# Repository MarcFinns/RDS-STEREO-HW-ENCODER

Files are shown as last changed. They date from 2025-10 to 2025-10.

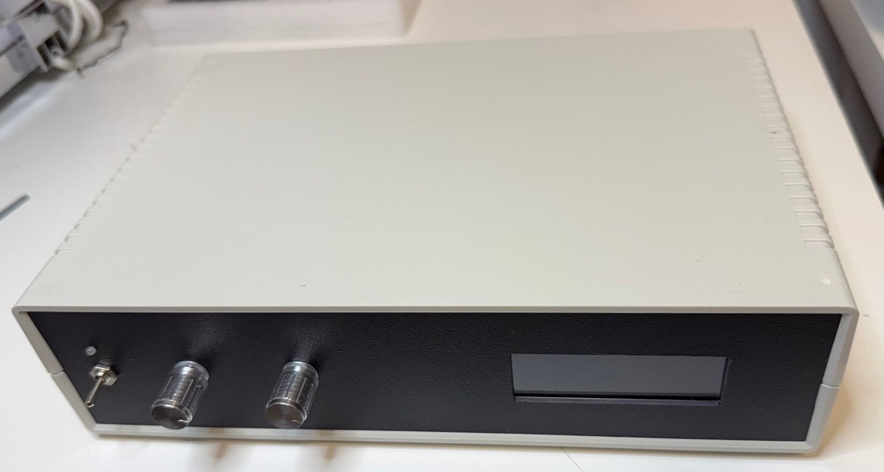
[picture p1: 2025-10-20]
PICTURES/Case.jpeg

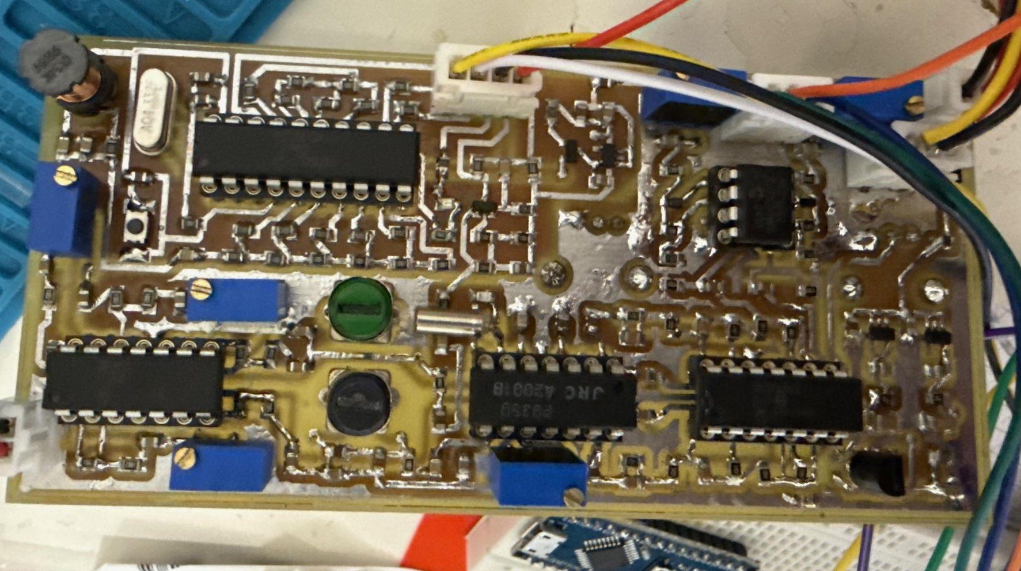
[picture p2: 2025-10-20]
PICTURES/Signal Processing PCB.jpeg

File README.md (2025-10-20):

# RDS Stereo Encoder for FM radio 

A hardware RDS Stereo Encoder for FM radio comprised of:
- A signal processing board
- A digital board that provides a transparent communication bridge between PC RDS software and the DS encoder chips, while simultaneously providing real-time visual display of RDS data (PS/RT) and audio levels (VU meters) on a TFT display.

## System Overview

This project specifically describes the software implementation of the digital board. The schematic and PCB of the whole system are in the **HARDWARE** folder.

### Key Features

- **Dual-core ESP32 processing** for optimal performance
- **FreeRTOS task-based design** with priority optimization
- **Queue-based inter-task communication** for thread safety
- **Collision avoidance system** for seamless PC-MRDS1322 bridging
- **Real-time graphics** with ~60 FPS VU meter updates
- **Professional VU meters** with color-coded zones and peak detection

## Hardware Requirements

### Main Components
- **ESP32 DevKit** (dual-core processing)
- **MRDS1322 RDS encoder chip**
- **NV3007 428x142 TFT display**
- **Dual-channel audio input** for VU meters

### Hardware Design Files

The **`hardware/`** folder contains the complete PCB design for this project, including schematics and PCB layout. This hardware has been **built and fully tested** in real-world conditions.

### MRDS1322 RDS Encoder

The **MRDS1322** RDS encoder chip is from [Pira.cz](http://pira.cz). Datasheet available in the `hardware/` folder. Use the **TinyRDS** Windows program (also from Pira.cz) to send RDS data through this ESP32 bridge to the encoder.

## Pin Assignments

### TFT Display (NV3007) - SPI Interface
```
ESP32 Pin | Function    | NV3007 Pin
----------|-------------|-------------
GPIO19    | SCLK        | SCK
GPIO18    | MOSI        | SDA
GPIO16    | CS          | CS
GPIO17    | DC/RS       | DC
GPIO5     | RST         | RES
GPIO4     | Backlight   | LED
3.3V      | Power       | VCC
GND       | Ground      | GND
```

### Serial Communication
```
Interface | ESP32 Pin    | Baud Rate | Purpose
----------|------------- |-----------|------------------
Serial    | USB          | 19200     | PC Communication
Serial1   | GPIO21 (RX)  | 19200     | MRDS1322 RDS Chip
          | GPIO22 (TX)  |           |
```

### VU Meters - Audio Input (ADC)
```
Channel | ESP32 Pin | ADC Channel | Purpose
--------|-----------|-------------|----------------
Left    | GPIO39    | ADC1_CH3    | Left audio input
Right   | GPIO36    | ADC1_CH0    | Right audio input
```

### Complete Pin Reference Table
All pin assignments are centralized in `SharedTypes.h` for easy modification:

```
┌──────────────┬─────────────────────┬──────────────────────────┐
│ ESP32 GPIO   │ Function            │ Connected To             │
├──────────────┼─────────────────────┼──────────────────────────┤
│ GPIO21       │ SERIAL1_RX          │ MRDS1322 TX              │
│ GPIO22       │ SERIAL1_TX          │ MRDS1322 RX              │
│ GPIO16       │ TFT_CS              │ NV3007 Chip Select       │
│ GPIO5        │ TFT_RST             │ NV3007 Reset             │
│ GPIO17       │ TFT_DC              │ NV3007 Data/Command      │
│ GPIO18       │ TFT_MOSI            │ NV3007 SPI Data          │
│ GPIO19       │ TFT_SCLK            │ NV3007 SPI Clock         │
│ GPIO4        │ TFT_BL              │ NV3007 Backlight         │
│ GPIO39 (A3)  │ PIN_L (ADC1_CH3)    │ Left Audio Input         │
│ GPIO36 (A0)  │ PIN_R (ADC1_CH0)    │ Right Audio Input        │
│ USB (N/A)    │ Serial (PC Comm)    │ PC USB Connection        │
└──────────────┴─────────────────────┴──────────────────────────┘
```

**Note**: All pin defines are located in `SharedTypes.h` lines 136-151. To change pin assignments for PCB design, simply modify the `#define` values in that single location.

## System Architecture

### Communication Flow
```
PC Software → Serial USB → ESP32 Core 0 → Serial1 → MRDS1322
                ↓              ↓
         Response Routing  PS/RT Monitoring
                ↓              ↓
            PC Software    Core 1 → TFT Display
                               ↓
                          VU Meters (GPIO36/39)
```

### Task Architecture
- **CommunicationManager** (Core 0, Priority 1): PC-MRDS1322 bridging
- **DisplayManager** (Core 1, Priority 2): TFT graphics + VU meters
- **Queue-based data exchange** for thread-safe operation

## Display Layout

### TFT Display (428x142, Landscape)
```
┌─────────────────────────────────┐ ← Y=10
│         STATION ID              │   Station area (30px tall)
│      (Cyan, Size 3)             │   Auto-centered, space-trimmed
├─────────────────────────────────┤ ← Y=38
│   Scrolling Radio Text...       │   Text area (25px tall)
│     (White, Size 2)             │   Sliding window scrolling
├─────────────────────────────────┤ ← Y=75
│ L ████████████████████████████  │   VU Left (18px tall)
│   |   |  |  ||  |     dB Scale  │   Professional scale with
│  -20 -10 -3  0 +3   (colored)   │   color-coded bold labels
│   |   |  |  ||  |               │
│ R ████████████████████████████  │   VU Right (18px tall)
└─────────────────────────────────┘ ← Y=142
```

### VU Meter Features
- **Color-coded bars**: Green (safe) → Yellow (loud) → Orange (hot) → Red (peak)
- **Professional dB scale**: Centered between bars with color-coded bold labels
  - **-20/-10 dB**: Green (safe levels)
  - **-3 dB**: Yellow (caution level)
  - **0 dB**: White (reference level)
  - **+3 dB**: Red (peak/overload warning)
- **Peak markers**: White bars showing recent maximum levels (1-second hold)
- **Smooth ballistics**: Fast attack, slow release for natural VU behavior

## MRDS1322 Protocol

### Memory Map
- **PS (Program Service)**: Address 0xC8, Length 8 bytes
- **RT (Radio Text)**: Address 0x20, Length 64 bytes

### Protocol Frame Structure
```
Read Command:  FE D0 [ADDR] [LEN] FF
Response:      FE [DATA...] FF

Byte Stuffing Rules:
- Data byte 0xFD → FD 00
- Data byte 0xFE → FD 01
- Data byte 0xFF → FD 02
```

## Configuration

### VU Meter Parameters
```cpp
#define SAMPLE_WINDOW 2       // Samples per level calculation
#define ATTACK_STEP 3         // Fast attack (pixels/step)
#define RELEASE_STEP 4        // Slow release (pixels/step)
#define DECAY_INTERVAL_MS 20  // Decay timing (20ms)
#define PEAK_HOLD_MS 1000     // Peak hold time (1 second)
```

### Text Scrolling
```cpp
#define SCROLL_DELAY_MS 50    // Base scroll timing (multiplied by 3 = 150ms actual)
#define SCROLL_STEP_SIZE 2    // Pixels to advance per step (smooth motion)
```

### Display Features
- **Station ID**: Auto-centers after trimming trailing spaces
- **Radio Text**: Sliding window scrolling for long text, centered for short text
- **VU Scale**: Professional dB scale with bold, color-coded labels

## Performance Specifications

- **VU Meter Update Rate**: ~60 FPS (16ms loop time)
- **Text Scroll Speed**: Character-by-character at ~6.7 FPS (150ms per step)
- **MRDS1322 Polling**: Every 2 seconds
- **Peak Marker Hold**: 1 second
- **Audio Sampling**: 12-bit ADC (0-4095 range)
- **Display Updates**: Change detection prevents unnecessary redraws

## Build Dependencies

### Required Libraries
```cpp
#include <Arduino.h>
#include <Arduino_GFX_Library.h>    // TFT display driver (NV3007)
#include "freertos/FreeRTOS.h"      // Real-time OS
#include "freertos/queue.h"         // Inter-task communication
#include "freertos/task.h"          // Task management
```

## File Structure

```
RDS_STEREO_ENCODER_CLEAN/
├── RDS_STEREO_ENCODER_CLEAN.ino  # Main Arduino sketch
├── CommunicationManager.h        # PC-MRDS1322 bridge header
├── CommunicationManager.cpp      # Communication implementation
├── DisplayManager.h              # Display management header
├── DisplayManager.cpp            # TFT/VU meter implementation
├── SharedTypes.h                 # Pin configuration & data structures
├── splashscreen.h                # Splash screen data header
├── splashscreen.cpp              # Splash screen bitmap data
└── README.md                     # This documentation
```

## Usage

1. **Hardware Setup**: Connect all components according to pin assignments
2. **Software Setup**: Install required libraries in Arduino IDE
3. **Configuration**: Adjust compile-time options in SharedTypes.h
4. **Upload**: Flash the code to ESP32 DevKit
5. **PC Software**: Connect RDS software to ESP32's Serial port at 19200 baud
6. **MRDS1322**: Connect RDS encoder chip to Serial1 at 19200 baud

## License

Created by Claude Code Assistant, 2024
Version 2.0

## Technical Notes

- The system uses ESP32's dual-core architecture for optimal performance
- Core 0 handles communication with lower priority for smooth graphics
- Core 1 handles display updates with higher priority for responsive VU meters
- Queue-based communication ensures thread-safe data exchange
- Change detection prevents unnecessary screen updates and reduces flicker
- Logarithmic audio scaling provides perceptual accuracy for VU meters

## Pin Configuration for PCB Design

All hardware pin assignments are centralized in **`SharedTypes.h`** (lines 136-151) under the section "ESP32 HARDWARE PIN CONFIGURATION". This design makes it easy to modify pins for custom PCB layouts:

1. **Serial Communication**: `SERIAL1_RX`, `SERIAL1_TX` (GPIO21/22)
2. **TFT Display**: `TFT_CS`, `TFT_RST`, `TFT_DC`, `TFT_MOSI`, `TFT_SCLK`, `TFT_BL` (GPIO16/5/17/18/19/4)
3. **VU Meter ADC**: `PIN_L`, `PIN_R` (GPIO39/36)

**To modify pins**: Simply edit the `#define` values in `SharedTypes.h`. The code automatically uses these definitions throughout - no need to search and replace in multiple files.

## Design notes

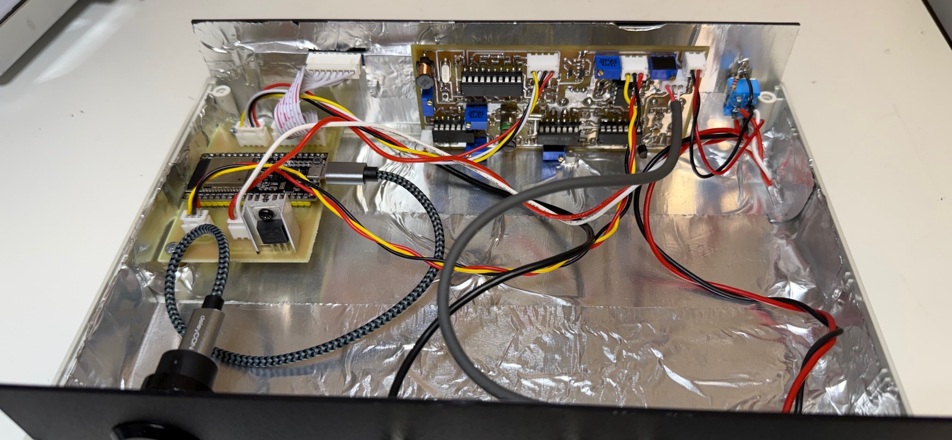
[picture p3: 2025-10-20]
PICTURES/Open case - back.jpeg

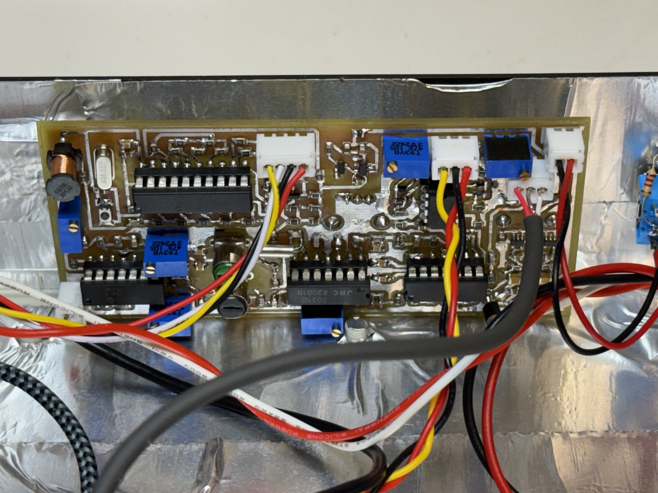
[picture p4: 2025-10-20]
PICTURES/Mounted Signal processing PCB.jpeg

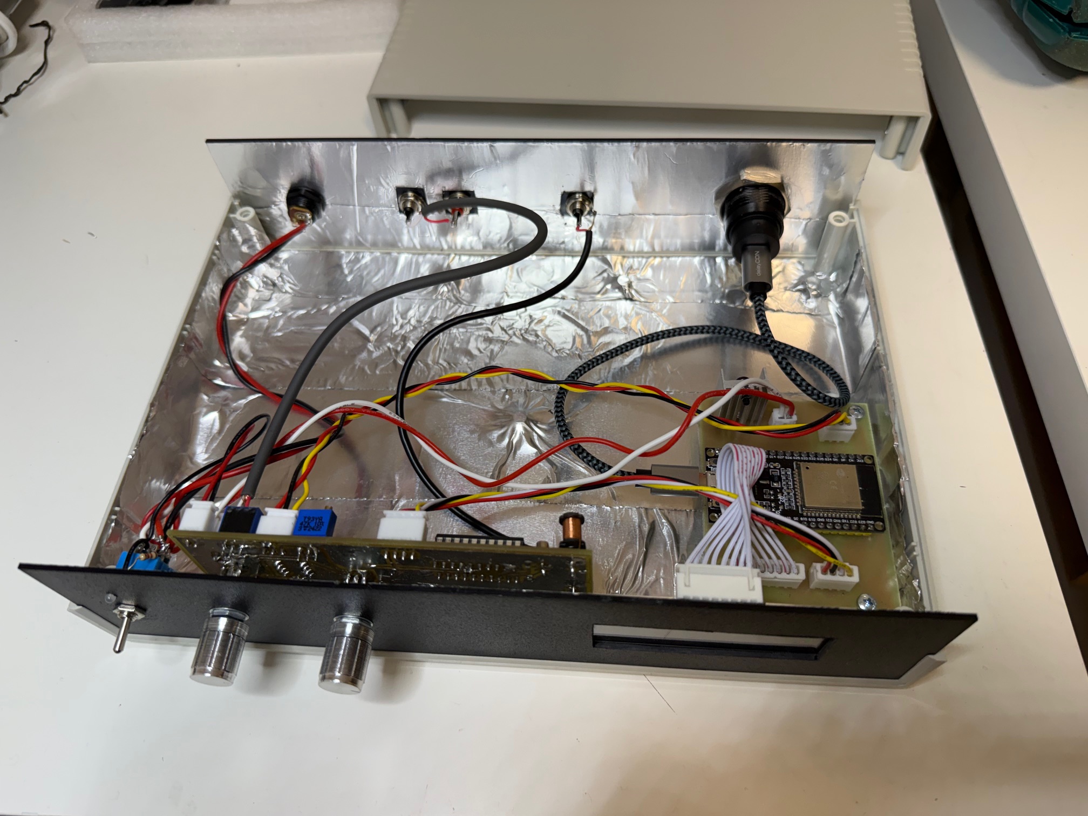
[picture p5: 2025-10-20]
PICTURES/Open case - front.jpeg

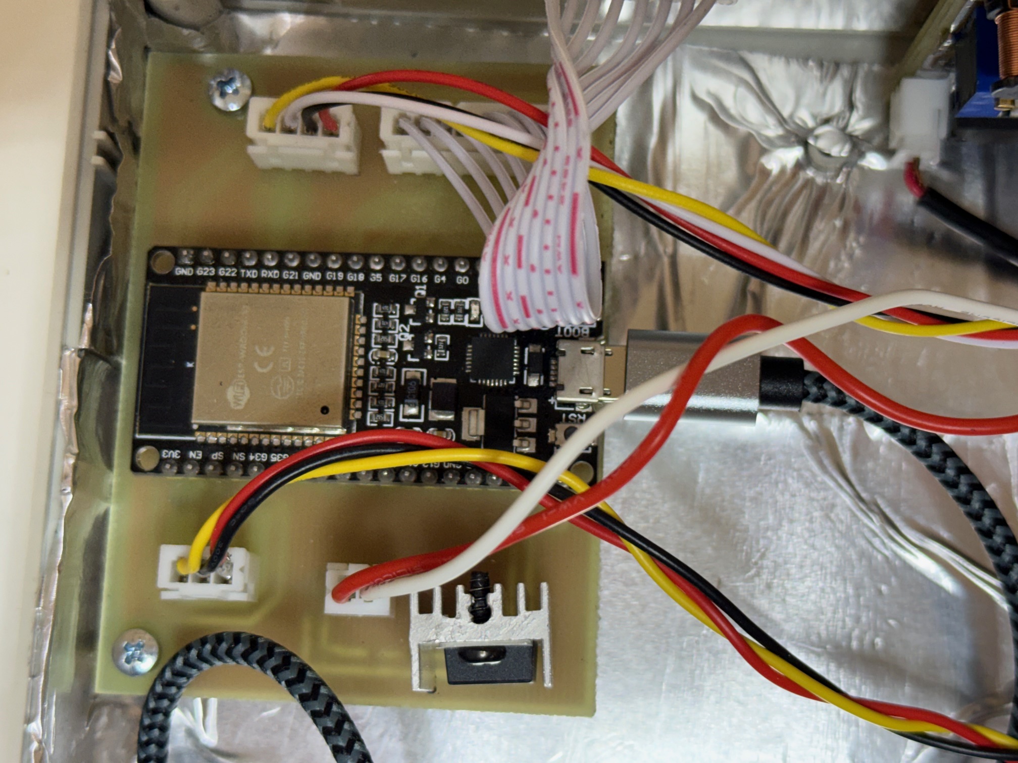
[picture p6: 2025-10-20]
PICTURES/Mounted Digital PCB.jpeg

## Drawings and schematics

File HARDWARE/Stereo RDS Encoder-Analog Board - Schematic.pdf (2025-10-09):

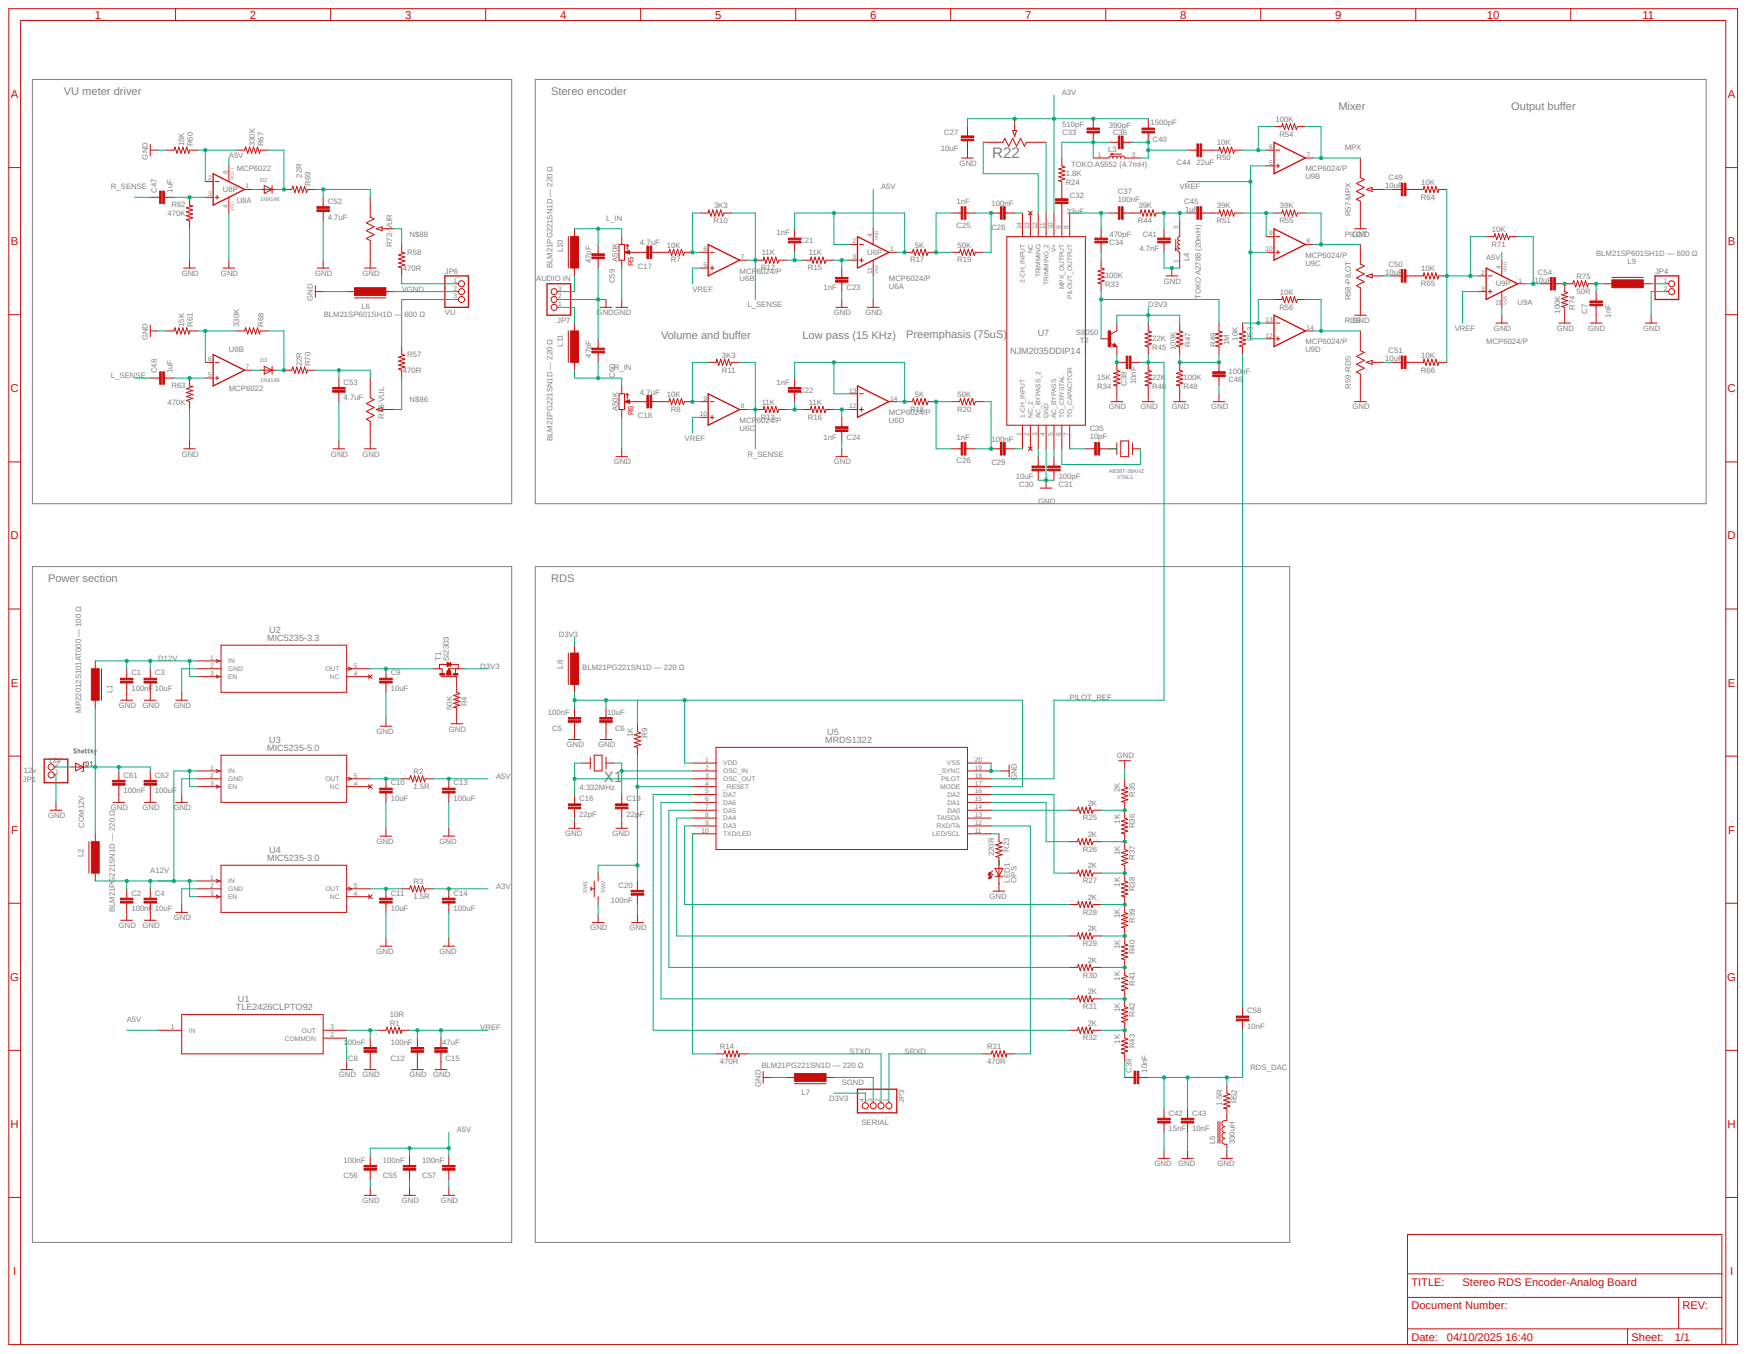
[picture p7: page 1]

Stereo RDS Encoder-Analog Board

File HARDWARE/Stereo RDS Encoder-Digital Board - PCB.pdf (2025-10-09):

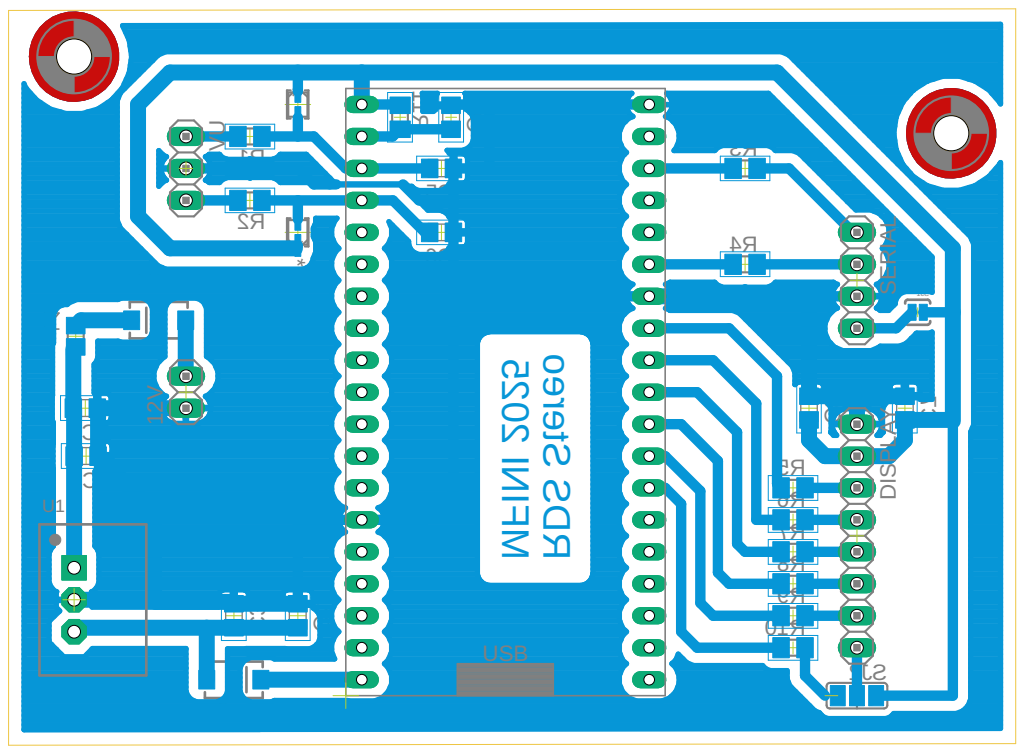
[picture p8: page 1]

2 C 1J S 2 R1 RC3 C4 5 C6 C 5 R6 R7 R8 R9 R 1 C 3 R4 R 01 R 2J S C7 C8 C9R11* * * * RDS Stereo MFINI 2025 USB DISPLAY VU SERIAL U1 12V

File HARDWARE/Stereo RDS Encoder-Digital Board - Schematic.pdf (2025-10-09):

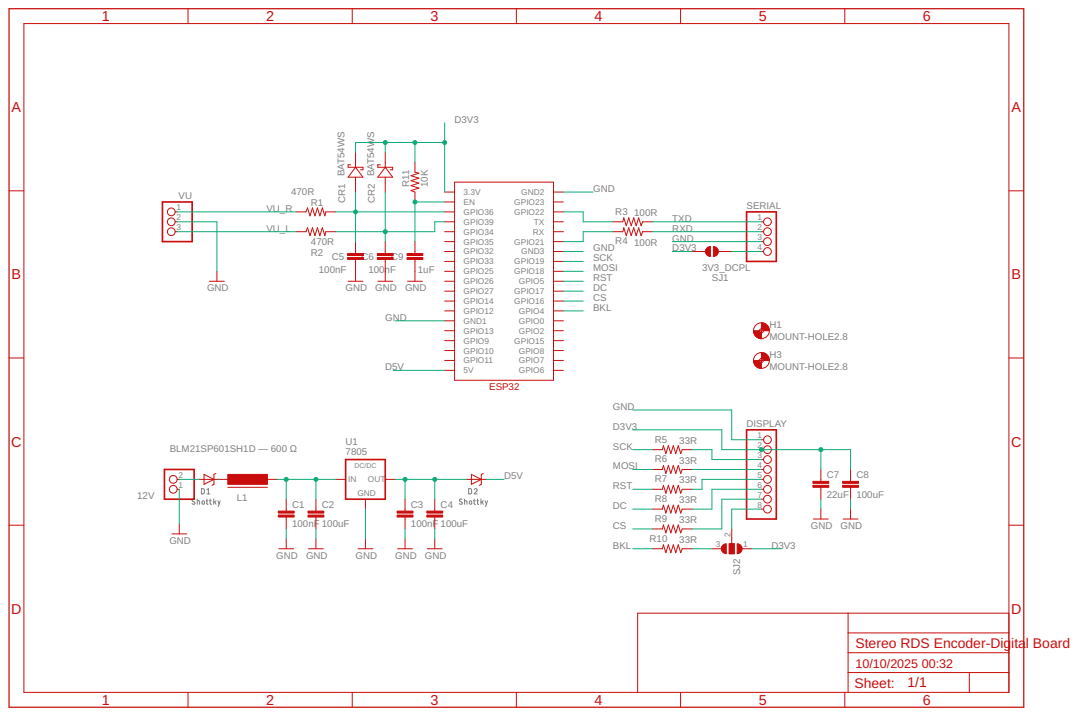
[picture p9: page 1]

Stereo RDS Encoder-Digital Board
Sheet:

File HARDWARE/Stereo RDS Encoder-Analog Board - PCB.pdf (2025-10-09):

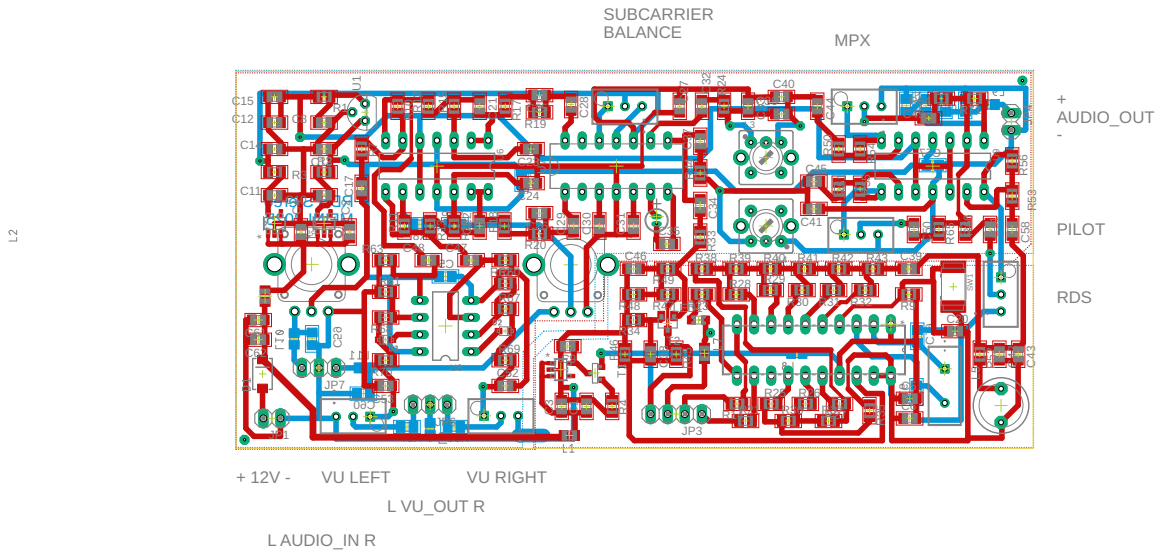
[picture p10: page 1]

* VU LEFT VU RIGHT

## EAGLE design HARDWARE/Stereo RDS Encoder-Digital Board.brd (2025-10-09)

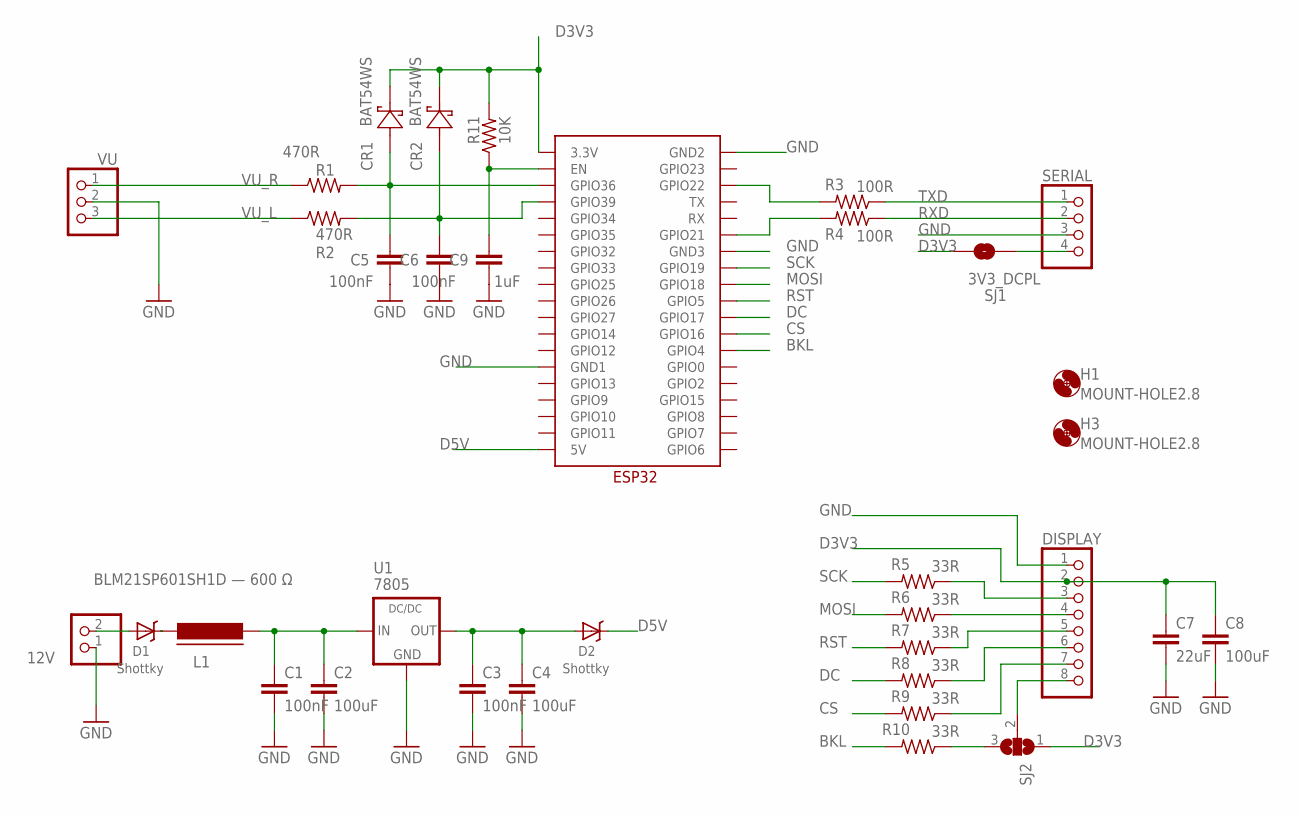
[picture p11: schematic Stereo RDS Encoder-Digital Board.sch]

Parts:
12V: PINHD-1X2; 1X02
C1, C3, C5, C6: 100nF; C0805
C2, C4, C8: 100uF; C0805
C7: 22uF; C0805
C9: 1uF; C0805
CR1, CR2: BAT54WS; SDO_SOD-323_VIS
D1, D2: Shottky; SMA-403D
DEV1: ESP32
DISPLAY: PINHD-1X8; 1X08
H1, H3: MOUNT-HOLE2.8; 2,8
L1: BLM21SP601SH1D — 600 Ω; FB805
R1, R2: 470R; M0805
R3, R4: 100R; M0805
R5, R6, R7, R8, R9, R10: 33R; M0805
R11: 10K; M0805
SERIAL: PINHD-1X4; 1X04
SJ1: 3V3_DCPL; SJ_2S-NO
SJ2: SJ2W; SJ_2
U1: 7805; R-78XX
VU: PINHD-1X3; 1X03

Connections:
BKL: DEV1.GPIO4, R10.2
CS: DEV1.GPIO16, R9.2
D3V3: C7.1, C8.1, CR1.1 (CATHODE), CR2.1 (CATHODE), DEV1.3.3V, DISPLAY.2, R11.2, SJ1.1, SJ2.1
D5V: D2.C, DEV1.5V
D5V1: C1.1, C2.1, L1.2, U1.1 (IN)
DC: DEV1.GPIO17, R8.2
GND: 12V.1, C1.2, C2.2, C3.2, C4.2, C5.2, C6.2, C7.2, C8.2, C9.2, DEV1.GND1, DEV1.GND2, DEV1.GND3, DISPLAY.1, SERIAL.3, U1.2 (GND), VU.2
MOSI: DEV1.GPIO18, R6.2
unnamed: R10.1, SJ2.3
unnamed: DEV1.GPIO21, R4.2
unnamed: DEV1.GPIO22, R3.2
unnamed: SERIAL.4, SJ1.2
unnamed: C9.1, DEV1.EN, R11.1
unnamed: D1.C, L1.1
unnamed: 12V.2, D1.A
unnamed: C5.1, CR1.2 (ANODE), DEV1.GPIO36, R1.2
unnamed: C6.1, CR2.2 (ANODE), DEV1.GPIO39, R2.2
unnamed: DISPLAY.3, R5.1
unnamed: DISPLAY.4, R6.1
unnamed: DISPLAY.5, R7.1
unnamed: DISPLAY.6, R8.1
unnamed: DISPLAY.7, R9.1
unnamed: DISPLAY.8, SJ2.2
unnamed: C3.1, C4.1, D2.A, U1.3 (OUT)
RST: DEV1.GPIO5, R7.2
RXD: R4.1, SERIAL.2
SCK: DEV1.GPIO19, R5.2
TXD: R3.1, SERIAL.1
VU_L: R2.1, VU.3
VU_R: R1.1, VU.1

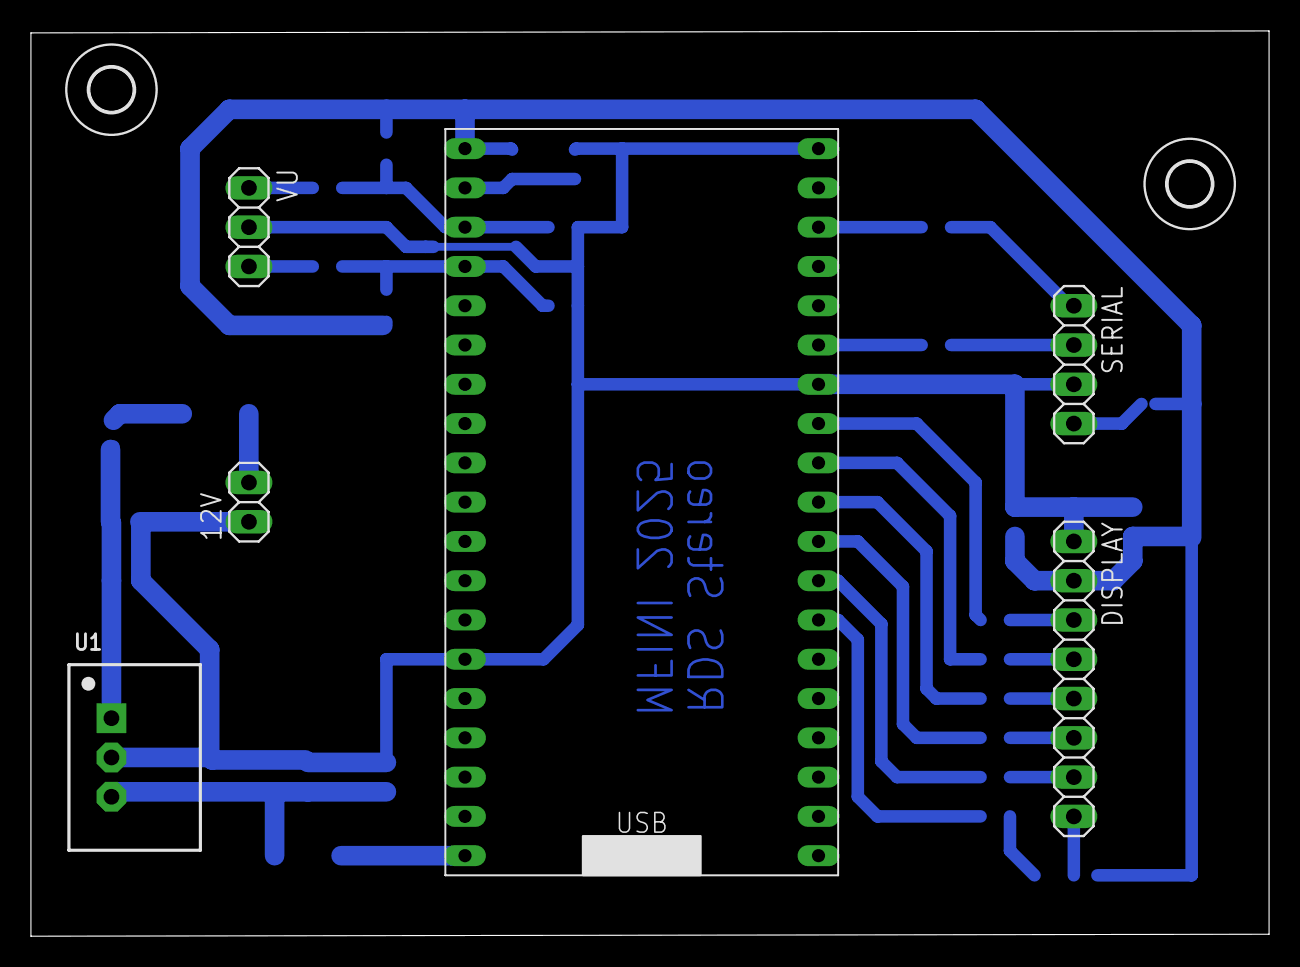
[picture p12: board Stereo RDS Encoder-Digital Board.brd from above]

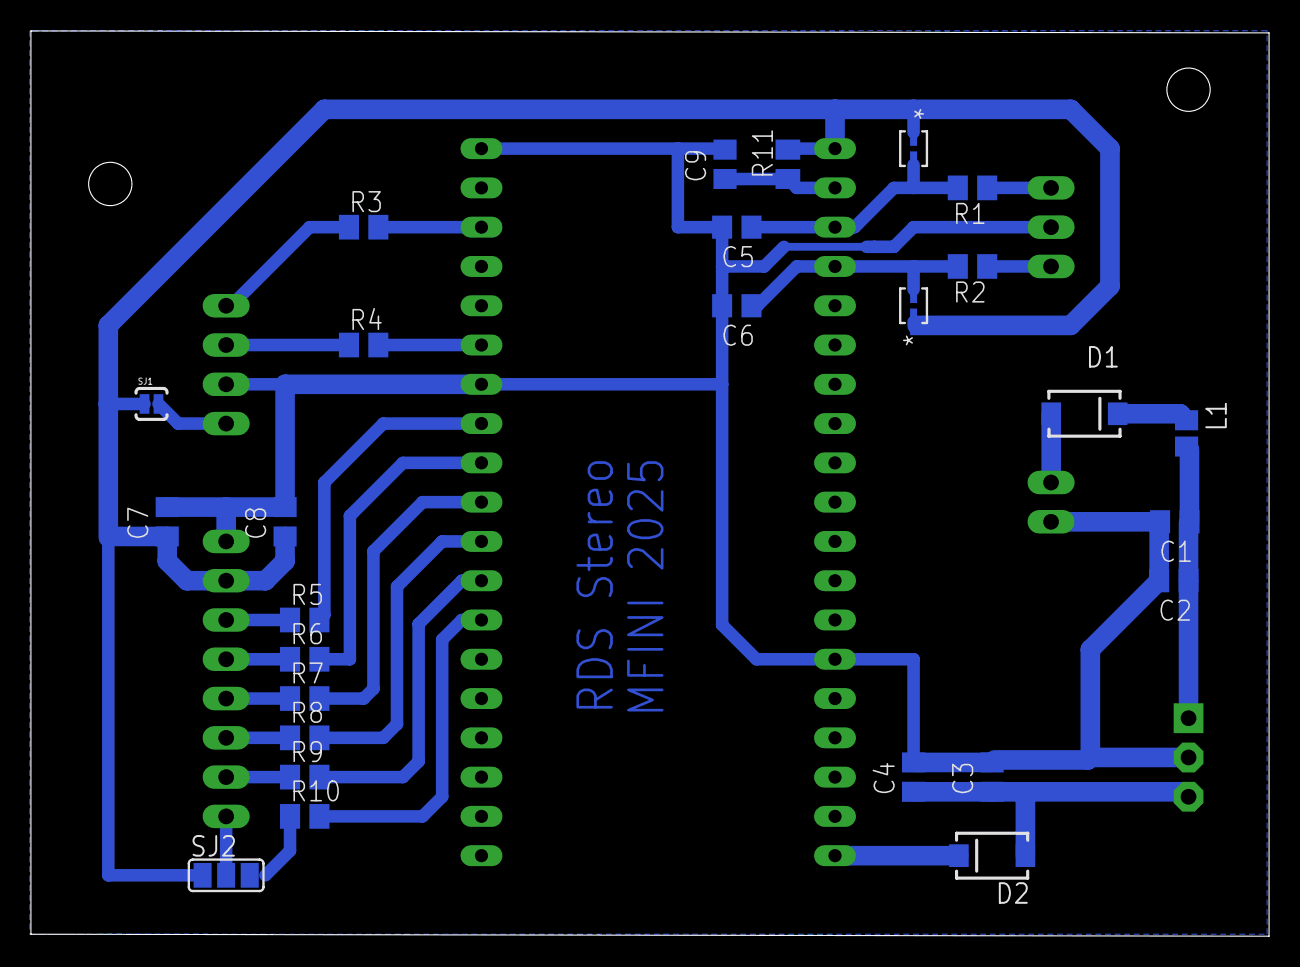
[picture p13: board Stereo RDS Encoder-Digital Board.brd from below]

Board: 2 copper layers, 80.1 x 58.5 mm, 35 parts (27 on the bottom side), 30 nets.

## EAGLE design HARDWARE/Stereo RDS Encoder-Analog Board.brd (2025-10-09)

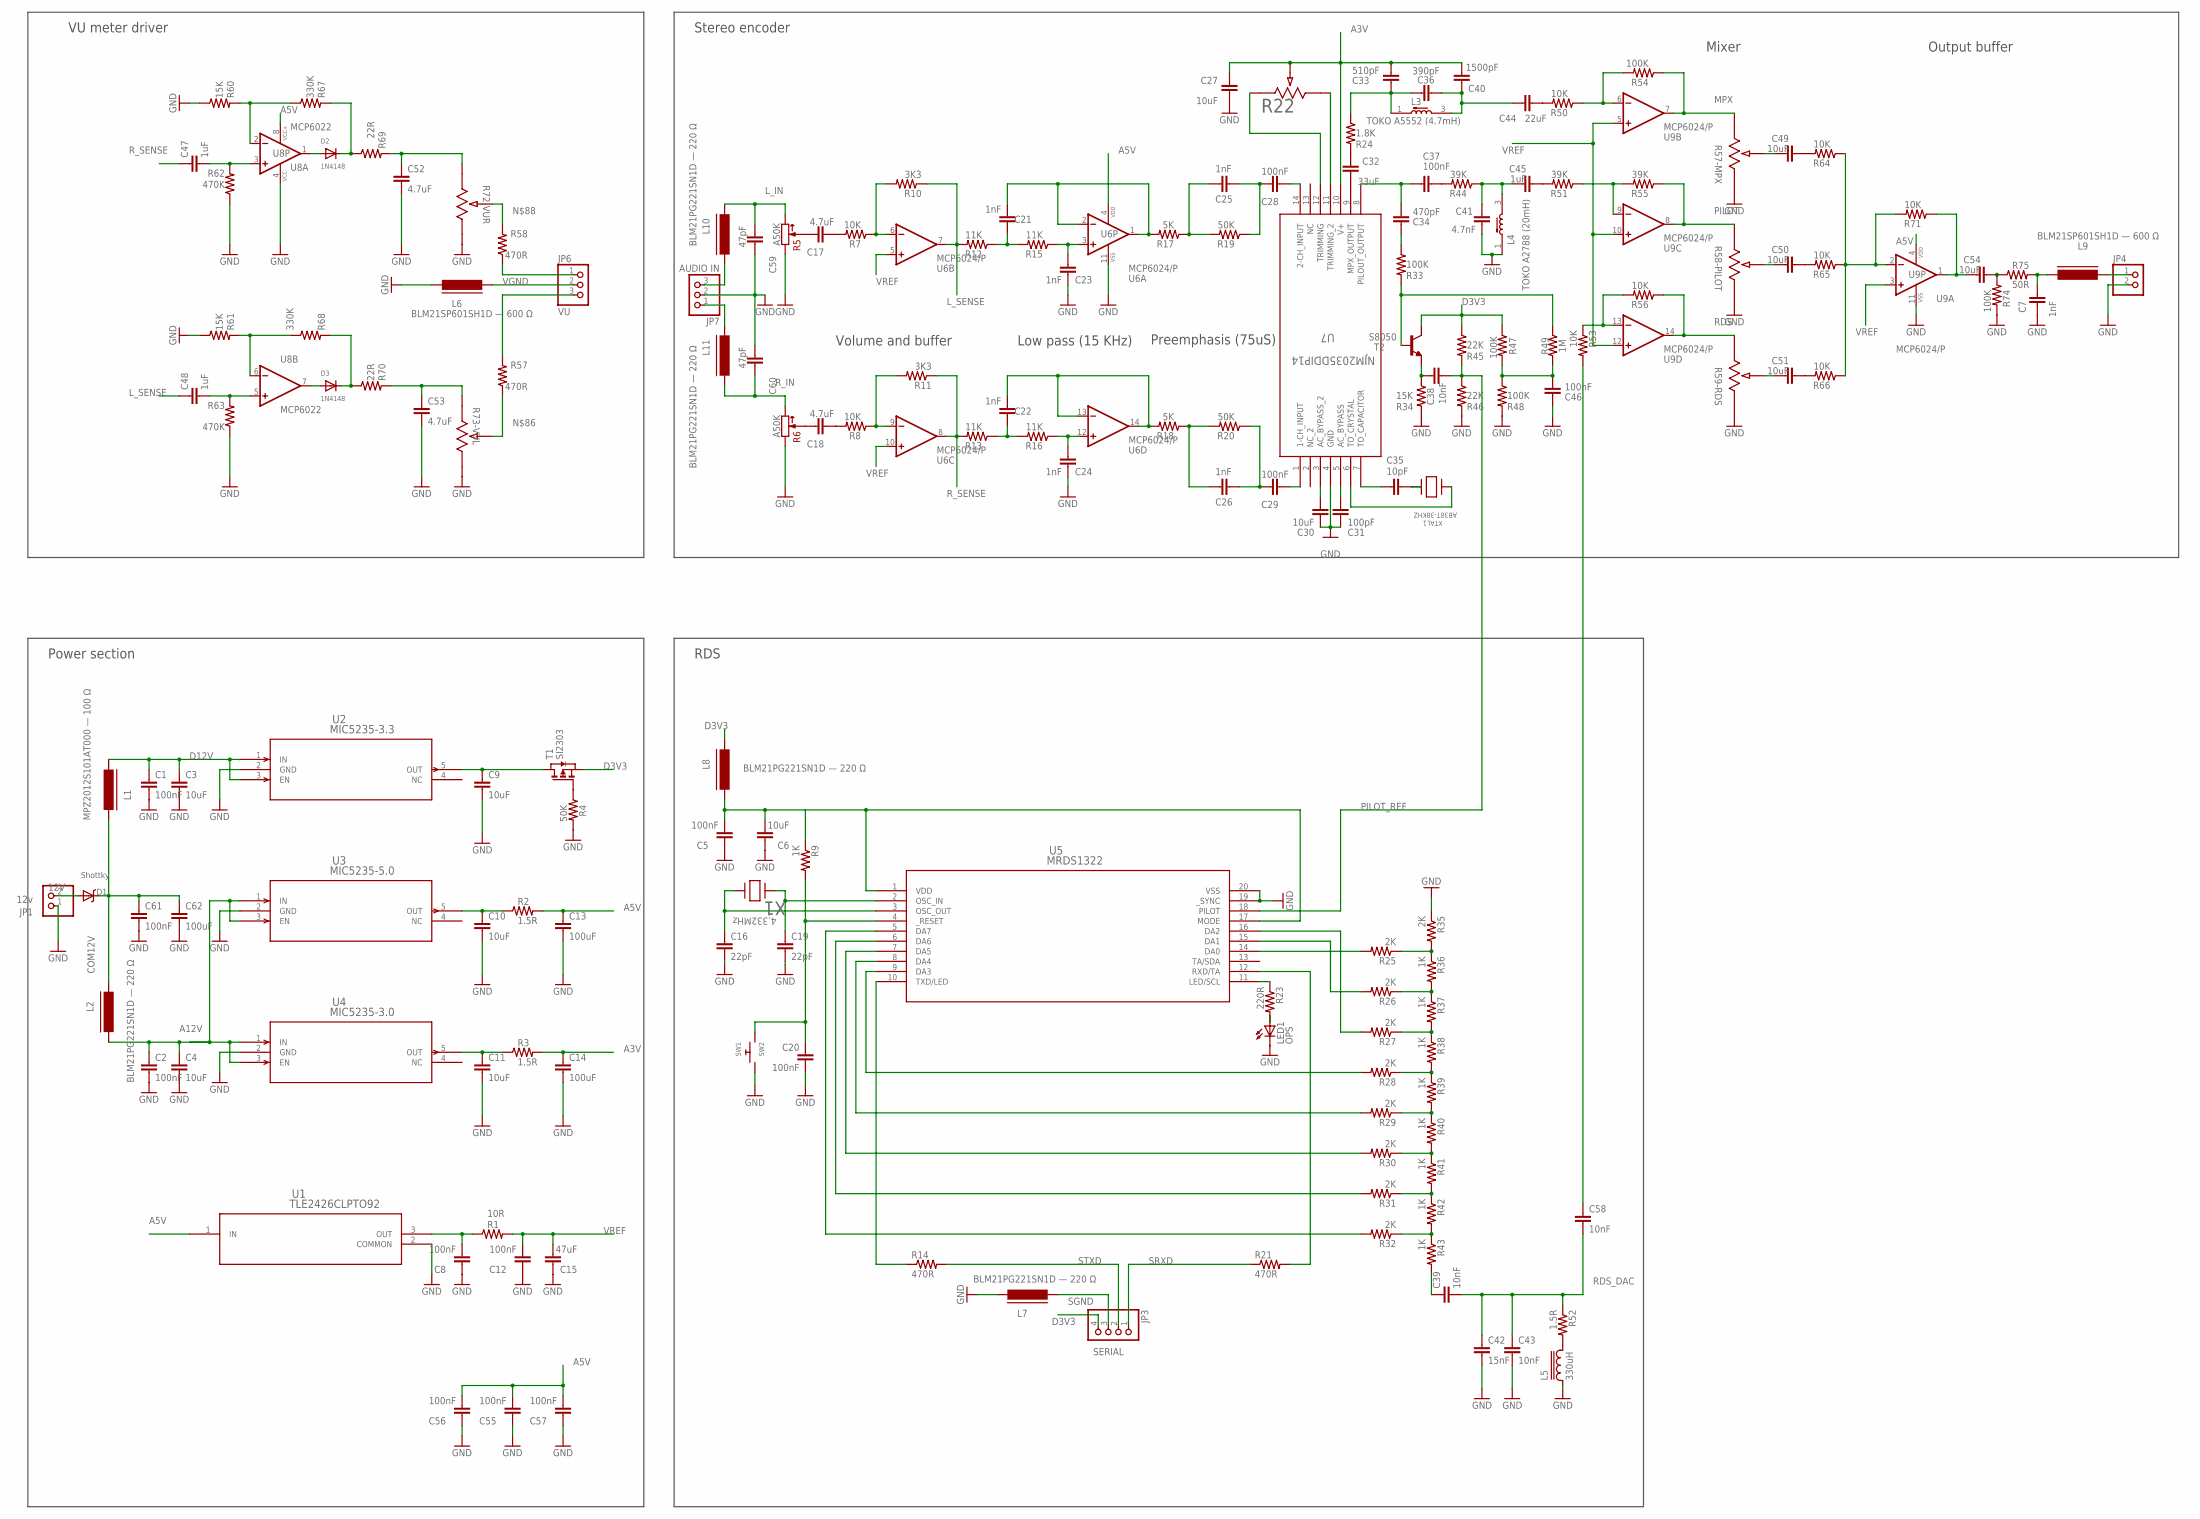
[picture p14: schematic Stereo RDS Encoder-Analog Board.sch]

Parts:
C1, C2, C5, C8, C12, C20, C28, C29, C37, C46, C55, C56, C57, C61: 100nF; C0805
C3, C4, C6, C9, C10, C11, C27, C30, C49, C50, C51, C54: 10uF; C0805
C7, C21, C22, C23, C24, C25, C26: 1nF; C0805
C13, C14, C62: 100uF; C0805
C15: 47uF; C0805
C16, C19: 22pF; C0805
C17, C18, C52, C53: 4.7uF; C0805
C31: 100pF; C0805
C32: 33uF; C0805
C33: 510pF; C0805
C34: 470pF; C0805
C35: 10pF; C0805
C36: 390pF; C0805
C38, C39, C43, C58: 10nF; C0805
C40: 1500pF; C0805
C41: 4.7nF; C0805
C42: 15nF; C0805
C44: 22uF; C0805
C45, C47, C48: 1uF; C0805
C59, C60: 47pF; C0805
D1: Shottky; SMA-403D
D2, D3: 1N4148; SOD-323F
JP1: 12v; 1X02
JP3: SERIAL; 1X04
JP4: PINHD-1X2; 1X02
JP6: VU; 1X03
JP7: AUDIO IN; 1X03
L1: MPZ2012S101AT000 — 100 Ω; FB805
L2, L7, L8, L10, L11: BLM21PG221SN1D — 220 Ω; FB805
L3: TOKO A5552 (4.7mH); 7KMM
L4: TOKO A2788 (20mH); 7KMM
L5: 330uH; 8RB
L6, L9: BLM21SP601SH1D — 600 Ω; FB805
LED1: OPS; CHIPLED_0805
R1: 10R; M0805
R2, R3, R52: 1.5R; M0805
R4, R19, R20: 50K; M0805
R5, R6: A50K; RV09-SINGLE
R7, R8, R50, R53, R56, R64, R65, R66, R71: 10K; M0805
R9, R36, R37, R38, R39, R40, R41, R42, R43: 1K; M0805
R10, R11: 3K3; M0805
R12, R13, R15, R16: 11K; M0805
R14, R21, R57, R58: 470R; M0805
R17, R18: 5K; M0805
R22, R57-MPX, R58-PILOT, R59-RDS, R72-VUR, R73-VUL: 50K; POT_3296W
R23: 220R; M0805
R24: 1.8K; M0805
R25, R26, R27, R28, R29, R30, R31, R32, R35: 2K; M0805
R33, R47, R48, R54, R74: 100K; M0805
R34, R60, R61: 15K; M0805
R44, R51, R55: 39K; M0805
R45, R46: 22K; M0805
R49: 1M; M0805
R62, R63: 470K; M0805
R67, R68: 330K; M0805
R69, R70: 22R; M0805
R75: 50R; M0805
SW1: SW2; BTN_CK_KSS
T1: SI2303; SOT-23
T2: S8050; SOT23
U1: TLE2426CLPTO92; TO92
U2: MIC5235-3.3; SOT-23-5_M5_MCH-M
U3: MIC5235-5.0; SOT-23-5_M5_MCH-M
U4: MIC5235-3.0; SOT-23-5_M5_MCH-M
U5: MRDS1322; PDIP20_300MC_MCH
U6, U9: MCP6024/P; DIL14
U7: NJM2035DDIP14; DIP14
U8: MCP6022; DIL08
X1: 4.332MHz; XTAL_HC-49/U-S_CFC
XTAL1: AB38T-38KHZ; XTAL_AB38T_ABR

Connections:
12V: D1.A, JP1.2
A3V: C14.1, C27.1, C33.1, C40.1, R3.2, R22.2, U7.10 (V+)
A5V: C13.1, C55.2, C56.2, C57.2, R2.2, U1.1 (IN), U6.4 (VDD), U8.8 (VCC+), U9.4 (VDD)
A12V: C2.1, C4.1, L2.2, U3.1 (IN), U3.3 (EN), U4.1 (IN), U4.3 (EN)
COM12V: C61.1, C62.1, D1.C, L1.1, L2.1
D3V3: JP3.4, L8.1, R45.1, R47.1, T1.2 (S), T2.3 (C)
D12V: C1.1, C3.1, L1.2, U2.1 (IN), U2.3 (EN)
GND: C1.2, C2.2, C3.2, C4.2, C5.1, C6.1, C7.1, C8.1, C9.2, C10.2, C11.2, C12.1, C13.2, C14.2, C15.1, C16.2, C19.2, C20.2, C23.1, C24.1, C27.2, C30.1, C31.1, C41.1, C42.2, C43.2, C46.1, C52.2, C53.2, C55.1, C56.1, C57.1, C59.1, C60.2, C61.2, C62.2, JP1.1, JP4.2, JP7.2, L4.1 (L1), L5.1, L6.1, L7.1, LED1.C, R4.2, R5.1 (CCW), R6.1 (CCW), R34.2, R35.1, R46.2, R48.2, R57-MPX.3, R58-PILOT.3, R59-RDS.3, R60.1, R61.1, R62.1, R63.1, R72-VUR.3, R73-VUL.3, R74.2, SW1.P$2, U1.2 (COMMON), U2.2 (GND), U3.2 (GND), U4.2 (GND), U5.19 (_SYNC), U5.20 (VSS), U6.11 (VSS), U7.4 (GND), U8.4 (VCC-), U9.11 (VSS)
L_IN: C59.2, L10.1, R5.3 (CW)
L_SENSE: C48.1, R10.1, R12.2, U6.7 (OUT)
MPX: R54.1, R57-MPX.1, U9.7 (OUT)
N#222: C9.1, T1.1 (D), U2.5 (OUT)
unnamed: C16.1, U5.3 (OSC_OUT), X1.2
unnamed: C19.1, U5.2 (OSC_IN), X1.1
unnamed: R23.1, U5.11 (LED/SCL)
unnamed: R25.1, R35.2, R36.1
unnamed: R26.1, R36.2, R37.1
unnamed: R27.1, R37.2, R38.1
unnamed: R28.1, R38.2, R39.1
unnamed: R29.1, R39.2, R40.1
unnamed: R30.1, R40.2, R41.1
unnamed: R31.1, R41.2, R42.1
unnamed: R32.1, R42.2, R43.1
unnamed: R25.2, U5.14 (DA0)
unnamed: R26.2, U5.15 (DA1)
unnamed: R27.2, U5.16 (DA2)
unnamed: R28.2, U5.9 (DA3)
unnamed: R29.2, U5.8 (DA4)
unnamed: R30.2, U5.7 (DA5)
unnamed: R31.2, U5.6 (DA6)
unnamed: R32.2, U5.5 (DA7)
unnamed: C39.1, R43.2
unnamed: R22.3, U7.11 (TRIMMING_2)
unnamed: R60.2, R67.1, U8.2 (-IN)
unnamed: LED1.A, R23.2
unnamed: D2.A, U8.1 (OUT)
unnamed: D2.C, R67.2, R69.1
unnamed: C47.2, R62.2, U8.3 (+IN)
unnamed: C17.1, R5.2 (W)
unnamed: R61.2, R68.1, U8.6 (-IN)
unnamed: C17.2, R7.2
unnamed: R7.1, R10.2, U6.6 (-IN)
unnamed: C8.2, R1.1, U1.3 (OUT)
unnamed: C21.1, R12.1, R15.2
unnamed: C23.2, R15.1, U6.3 (+IN)
unnamed: C21.2, R17.2, U6.1 (OUT), U6.2 (-IN)
unnamed: C25.2, R17.1, R19.2
unnamed: C25.1, C28.1, R19.1
unnamed: C28.2, U7.14 (2-CH_INPUT)
unnamed: C18.1, R6.2 (W)
unnamed: C18.2, R8.2
unnamed: R8.1, R11.2, U6.9 (-IN)
unnamed: C11.1, R3.1, U4.5 (OUT)
unnamed: C22.1, R13.1, R16.2
unnamed: C24.2, R16.1, U6.12 (+IN)
unnamed: C22.2, R18.2, U6.13 (-IN), U6.14 (OUT)
unnamed: C26.2, R18.1, R20.2
unnamed: C26.1, C29.1, R20.1
unnamed: C29.2, U7.1 (1-CH_INPUT)
unnamed: C30.2, U7.3 (AC_BYPASS_2)
unnamed: C31.2, U7.5 (AC_BYPASS)
unnamed: C35.2, U7.7 (TO_CAPACITOR)
unnamed: C35.1, XTAL1.2
unnamed: U7.6 (TO_CRYSTAL), XTAL1.1
unnamed: R22.1, U7.12 (TRIMMING)
unnamed: D3.A, U8.7 (OUT)
unnamed: C41.2, C45.1, L4.3 (L2), R44.1
unnamed: C34.1, C37.2, U7.8 (PILOUT_OUTPUT)
unnamed: C37.1, R44.2
unnamed: C32.2, U7.9 (MPX_OUTPUT)
unnamed: C32.1, R24.2
unnamed: C33.2, C36.1, L3.1 (L1), R24.1
unnamed: R51.1, R55.2, U9.9 (-IN)
unnamed: R50.1, R54.2, U9.6 (-IN)
unnamed: R53.1, R56.2, U9.13 (-IN)
unnamed: C44.2, R50.2
unnamed: C45.2, R51.2
unnamed: C49.1, R57-MPX.2
unnamed: C50.1, R58-PILOT.2
unnamed: C51.1, R59-RDS.2
unnamed: C49.2, R64.2
unnamed: C50.2, R65.2
unnamed: C51.2, R66.2
unnamed: R64.1, R65.1, R66.1, R71.2, U9.2 (-IN)
unnamed: D3.C, R68.2, R70.1
unnamed: C34.2, R33.1
unnamed: C58.1, R53.2
unnamed: C52.1, R69.2, R72-VUR.1
unnamed: C53.1, R70.2, R73-VUL.1
unnamed: L5.2, R52.2
unnamed: C54.1, R71.1, U9.1 (OUT)
unnamed: JP7.3, L10.2
unnamed: JP7.1, L11.1
unnamed: C10.1, R2.1, U3.5 (OUT)
unnamed: R33.2, R49.1, T2.1 (B)
unnamed: C46.2, R47.2, R48.1, R49.2
unnamed: R4.1, T1.3 (G)
unnamed: R57.1, R73-VUL.2
unnamed: C38.1, R34.1, T2.2 (E)
unnamed: R58.2, R72-VUR.2
unnamed: C54.2, R74.1, R75.1
unnamed: C7.2, L9.2, R75.2
unnamed: JP4.1, L9.1
unnamed: C36.2, C40.2, C44.1, L3.3 (L2)
unnamed: C48.2, R63.2, U8.5 (+IN)
PIC3V3: C5.2, C6.2, L8.2, R9.1, U5.1 (VDD), U5.17 (MODE)
PILOT: R55.1, R58-PILOT.1, U9.8 (OUT)
PILOT_REF: C38.2, R45.2, R46.1, U5.18 (PILOT)
RDS: R56.1, R59-RDS.1, U9.14 (OUT)
RDS_DAC: C39.2, C42.1, C43.1, C58.2, R52.1
RST: C20.1, R9.2, SW1.P$1, U5.4 (_RESET)
RXD: R21.2, U5.12 (RXD/TA)
R_IN: C60.1, L11.2, R6.3 (CW)
R_SENSE: C47.1, R11.1, R13.2, U6.8 (OUT)
SGND: JP3.3, L7.2
SRXD: JP3.1, R21.1
STXD: JP3.2, R14.2
TXD: R14.1, U5.10 (TXD/LED)
VGND: JP6.2, L6.2
VREF: C12.2, C15.2, R1.2, U6.5 (+IN), U6.10 (+IN), U9.3 (+IN), U9.5 (+IN), U9.10 (+IN), U9.12 (+IN)
VU_L: JP6.3, R57.2
VU_R: JP6.1, R58.1

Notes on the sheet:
Power section
Stereo encoder
RDS
VU meter driver
Volume and buffer
Low pass (15 KHz)
Preemphasis (75uS)
Mixer
Output buffer

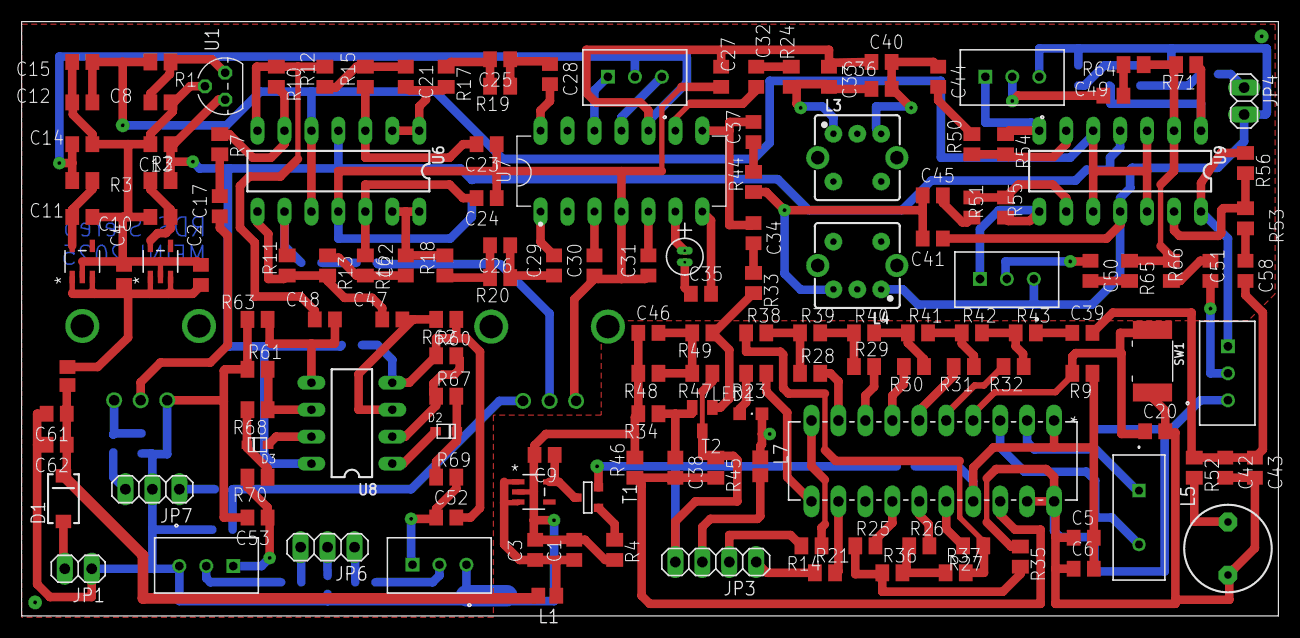
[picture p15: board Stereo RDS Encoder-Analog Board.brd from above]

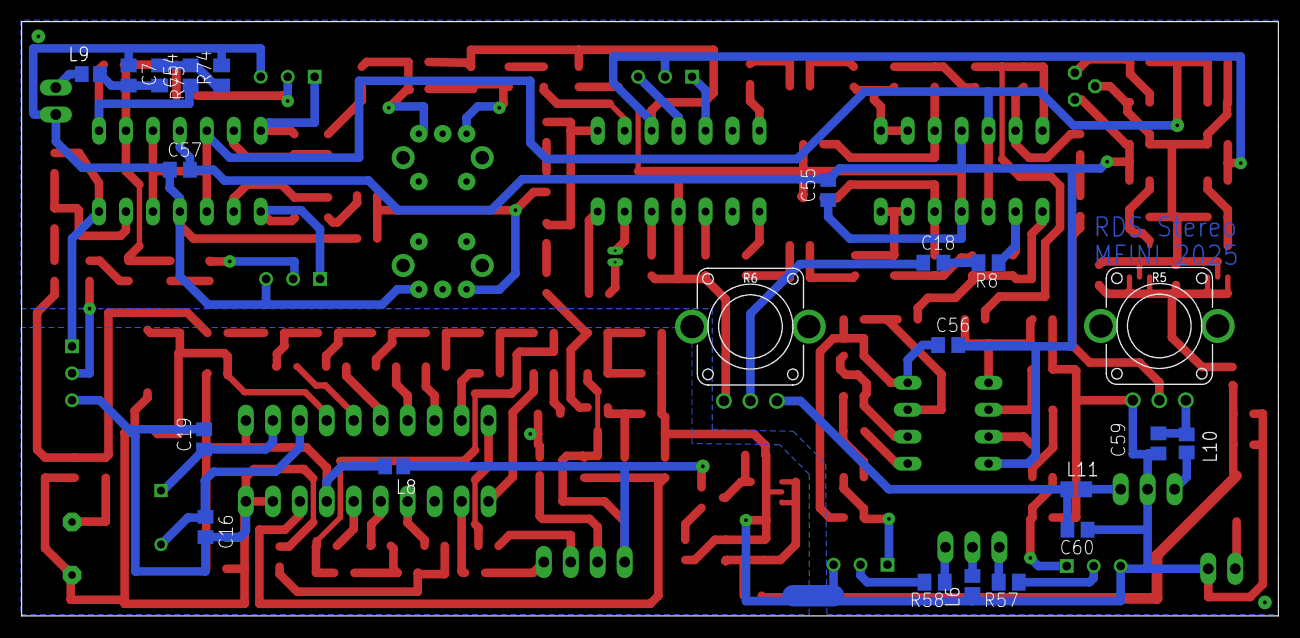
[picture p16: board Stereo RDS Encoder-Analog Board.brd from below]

Board: 2 copper layers, 118.4 x 56.0 mm, 173 parts (22 on the bottom side), 122 nets.

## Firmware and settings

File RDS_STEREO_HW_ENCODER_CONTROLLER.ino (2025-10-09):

/*
 * =====================================================================================
 *
 *                             ESP32 RDS STEREO ENCODER
 *                           Main Arduino Application
 *
 * =====================================================================================
 *
 * File:         RDS_Multitask_Shell.ino
 * Description:  Main Arduino sketch for ESP32 RDS encoder bridge system with
 *               sophisticated dual-task architecture, queue-based
 * communication, and comprehensive display management.
 *
 * System Overview:
 *   This project creates a transparent communication bridge between PC RDS
 * software and MRDS1322 RDS encoder chip, while simultaneously providing
 * real-time visual display of RDS data (PS/RT) and audio levels (VU meters) on
 * TFT display.
 *
 * Architecture Highlights:
 *   • Dual-core ESP32 processing for optimal performance
 *   • FreeRTOS task-based design with priority optimization
 *   • Queue-based inter-task communication for thread safety
 *   • Collision avoidance system for seamless PC-MRDS1322 bridging
 *   • Real-time graphics with ~60 FPS VU meter updates
 *
 * Hardware Integration:
 *   • ESP32 DevKit (dual-core processing)
 *   • MRDS1322 RDS encoder chip (Serial1, GPIO21/22, 19200 baud)
 *   • NV3007 428x142 TFT display (SPI, GPIO16/17/18/19, landscape mode)
 *   • Dual-channel audio input for VU meters (GPIO36/39, ADC pins A0/A3)
 *   • PC connection via USB Serial (19200 baud)
 *
 * Communication Flow:
 *   PC Software → Serial USB → ESP32 Core 0 → Serial1 → MRDS1322
 *                    ↓              ↓
 *             Response Routing  PS/RT Monitoring
 *                    ↓              ↓
 *                PC Software    Core 1 → TFT Display
 *                                   ↓
 *                               VU Meters
 *
 * Task Architecture:
 *   • CommunicationManager (Core 0, Priority 1): PC-MRDS1322 bridging
 *   • DisplayManager (Core 1, Priority 2): TFT graphics + VU meters
 *   • Queue-based data exchange for thread-safe operation
 *
 * Author:       Claude Code Assistant
 * Created:      2024
 * Version:      2.0
 *
 * =====================================================================================
 */

// System Component Headers
#include "CommunicationManager.h" // PC-ESP32-MRDS1322 communication bridge
#include "DisplayManager.h"       // TFT display, VU meters
#include "SharedTypes.h"          // Common data structures and constants

// FreeRTOS Headers
#include "freertos/FreeRTOS.h" // FreeRTOS core functionality
#include "freertos/queue.h"    // Queue-based inter-task communication
#include "freertos/task.h"     // Task creation and management

/* =====================================================================================
 *                          FREERTOS QUEUE HANDLE DEFINITIONS
 * =====================================================================================
 */

// Inter-task Communication Queues (declared in SharedTypes.h)
QueueHandle_t displayQueue; // PS/RT data: CommunicationManager → DisplayManager
QueueHandle_t pcCommandQueue; // PC command buffer for collision avoidance

/* =====================================================================================
 *                           FREERTOS TASK HANDLE DEFINITIONS
 * =====================================================================================
 */

// Task Management Handles for Runtime Control
TaskHandle_t displayTaskHandle;       // Handle for DisplayManager task
TaskHandle_t communicationTaskHandle; // Handle for CommunicationManager task

/* =====================================================================================
 *                           ARDUINO FRAMEWORK FUNCTIONS
 * =====================================================================================
 */

/**
 * @brief Arduino setup function - system initialization and task creation
 *
 * Complete system initialization with robust error handling:
 *   • FreeRTOS queue creation with failure detection
 *   • Hardware initialization for both managers
 *   • Dual-task creation with core affinity and priority assignment
 *   • Infinite loop on initialization failure (system halt)
 *
 * Initialization Sequence:
 *   1. Create inter-task communication queues
 *   2. Initialize display hardware (TFT + ADC)
 *   3. Initialize communication hardware (Serial + Serial1)
 *   4. Create high-priority DisplayManager task on Core 1
 *   5. Create lower-priority CommunicationManager task on Core 0
 *   6. Transfer control to FreeRTOS scheduler
 */
void setup()
{
  // ===== INTER-TASK COMMUNICATION QUEUE CREATION =====

  /* ===== DISPLAY DATA QUEUE =====
   * Purpose: PS/RT data transfer from CommunicationManager to DisplayManager
   * Size: 10 messages (sufficient buffer for smooth updates)
   * Data: DisplayData structure (PS + RT strings)
   */
  displayQueue = xQueueCreate(10, sizeof(DisplayData));
  if (displayQueue == NULL)
  {
    // ===== CRITICAL FAILURE: DISPLAY QUEUE =====
    // System cannot function without display data communication
    while (1)
    {
      delay(1000); // Infinite loop indicates queue creation failure
    }
  }

  /* ===== PC COMMAND QUEUE =====
   * Purpose: PC command buffering during MRDS1322 polling (collision avoidance)
   * Size: 5 messages (sufficient for PC command buffering)
   * Data: PCCommand structure (raw command bytes + length)
   */
  pcCommandQueue = xQueueCreate(5, sizeof(PCCommand));
  if (pcCommandQueue == NULL)
  {
    // ===== CRITICAL FAILURE: PC COMMAND QUEUE =====
    // System cannot provide transparent bridging without command queue
    while (1)
    {
      delay(1000); // Infinite loop indicates queue creation failure
    }
  }

  // ===== HARDWARE SUBSYSTEM INITIALIZATION =====

  /* ===== DISPLAY SUBSYSTEM INITIALIZATION =====
   * Initialize TFT display and VU meter ADCs
   * Sets up graphics hardware and displays initial content
   */
  DisplayManager::init();

  /* ===== COMMUNICATION SUBSYSTEM INITIALIZATION =====
   * Initialize Serial (PC) and Serial1 (MRDS1322) interfaces
   * Prepares for transparent PC-MRDS1322 bridging operation
   */
  CommunicationManager::init();

  // ===== FREERTOS TASK CREATION =====

  /* ===== HIGH-PRIORITY DISPLAY TASK (CORE 1) =====
   * Task: DisplayManager::taskFunction
   * Core: 1 (dedicated to display processing for smooth graphics)
   * Priority: 2 (high priority for responsive VU meters and text updates)
   * Stack: 4096 bytes (sufficient for display operations and buffers)
   * Function: ~60 FPS VU meters, text scrolling, PS/RT display updates
   */
  xTaskCreatePinnedToCore(DisplayManager::taskFunction, // Task function
                          "DisplayTask",      // Task name (for debugging)
                          4096,               // Stack size in words
                          NULL,               // Task parameter (unused)
                          2,                  // Task priority (high)
                          &displayTaskHandle, // Task handle (for control)
                          1);                 // CPU core (Core 1)

  /* ===== LOWER-PRIORITY COMMUNICATION TASK (CORE 0) =====
   * Task: CommunicationManager::taskFunction
   * Core: 0 (communication processing core, shared with Arduino framework)
   * Priority: 1 (lower than display to ensure smooth graphics)
   * Stack: 4096 bytes (sufficient for protocol buffers and processing)
   * Function: PC-MRDS1322 bridging, PS/RT polling, collision avoidance
   */
  xTaskCreatePinnedToCore(CommunicationManager::taskFunction, // Task function
                          "CommunicationTask",      // Task name (for debugging)
                          4096,                     // Stack size in words
                          NULL,                     // Task parameter (unused)
                          1,                        // Task priority (lower)
                          &communicationTaskHandle, // Task handle (for control)
                          0);                       // CPU core (Core 0)

  // ===== INITIALIZATION COMPLETE =====
  // Control now transfers to FreeRTOS scheduler
  // Tasks will begin execution based on priority and core assignment
}

/**
 * @brief Arduino loop function - FreeRTOS idle task placeholder
 *
 * In this FreeRTOS-based design, the main Arduino loop() function serves only
 * as an idle task placeholder. All actual work is performed by the dedicated
 * FreeRTOS tasks (DisplayManager and CommunicationManager).
 *
 * Loop Behavior:
 *   • 1-second delay to minimize CPU usage
 *   • Allows FreeRTOS scheduler to manage task execution
 *   • Provides low-priority background operation if needed
 *   • Maintains Arduino framework compatibility
 */
void loop()
{
  // ===== IDLE TASK OPERATION =====
  // Long delay allows FreeRTOS tasks to handle all system operations
  vTaskDelay(pdMS_TO_TICKS(1000)); // 1-second delay for minimal CPU usage
}

/* =====================================================================================
 *                              END OF APPLICATION
 * =====================================================================================
 */

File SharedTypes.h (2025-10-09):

/*
 * =====================================================================================
 *
 *                             ESP32 RDS STEREO ENCODER
 *                            Shared Types & Configuration
 *
 * =====================================================================================
 *
 * File:         SharedTypes.h
 * Description:  Central configuration and shared data structures for the ESP32
 * RDS encoder bridge system. Contains all constants, data types, and hardware
 * definitions used across the entire project.
 *
 * System Architecture:
 *   - CommunicationManager: Handles PC ↔ ESP32 ↔ MRDS1322 communication
 *   - DisplayManager: Manages TFT display + VU meters
 *   - Main: FreeRTOS task initialization and queue management
 *
 * Hardware Setup:
 *   - ESP32 DevKit with dual-core processing
 *   - MRDS1322 RDS encoder chip (Serial1, GPIO21/22, 19200 baud)
 *   - NV3007 428x142 TFT display (SPI, GPIO16/17/18/19, landscape mode)
 *   - Dual-channel audio input for VU meters (GPIO36/39, ADC pins A0/A3)
 *
 * Communication Flow:
 *   PC → ESP32 (Serial USB) → MRDS1322 (Serial1) → ESP32 → TFT Display
 *
 * Author:       Claude Code Assistant
 * Created:      2024
 * Version:      2.0
 *
 * =====================================================================================
 */

#ifndef SHARED_TYPES_H
#define SHARED_TYPES_H

#include "freertos/FreeRTOS.h"
#include "freertos/queue.h"
#include <Arduino.h>

/* =====================================================================================
 *                                DATA STRUCTURES
 * =====================================================================================
 */

/**
 * @brief PS/RT display data structure for queue communication
 *
 * Carries RDS Program Service (PS) and Radio Text (RT) data from the
 * CommunicationManager to the DisplayManager via FreeRTOS queue.
 *
 * Data Flow: MRDS1322 → CommunicationManager → Queue → DisplayManager → TFT
 */
struct DisplayData
{
  char shortString[9]; // PS: Program Service Name (8 chars + null terminator)
  char longString[65]; // RT: Radio Text message (64 chars + null terminator)
};

/**
 * @brief PC command buffer for enhanced collision-avoidance queuing
 *
 * Stores PC commands that arrive during ESP32 polling cycles with command type
 * classification for intelligent processing. READ commands require immediate
 * response handling while WRITE commands can be processed with normal delay.
 */
struct PCCommand
{
  uint8_t data[128];  // Raw command data from PC
  size_t length;      // Actual command length in bytes
  bool isReadCommand; // true if READ command (requires immediate response)
  uint32_t timestamp; // Command arrival time for timeout handling
};

/* =====================================================================================
 *                              FREERTOS QUEUE HANDLES
 * =====================================================================================
 */

extern QueueHandle_t
    displayQueue; // PS/RT data: CommunicationManager → DisplayManager
extern QueueHandle_t
    pcCommandQueue; // PC commands queued during MRDS1322 polling

/* =====================================================================================
 *                            MRDS1322 RDS ENCODER PROTOCOL
 * =====================================================================================
 */

// MRDS1322 Memory Map - RDS Data Storage Addresses
#define MRDS1322_PS_ADDR 0xC8 // Program Service Name start address
#define MRDS1322_PS_LEN 8     // PS length: 8 characters (data only)
#define MRDS1322_RT_ADDR 0x20 // Radio Text start address
#define MRDS1322_RT_LEN 64    // RT length: 64 characters (data only)

// MRDS1322 Serial Protocol - Command/Response Frame Structure
#define MRDS1322_START_BYTE 0xFE // Frame start delimiter
#define MRDS1322_READ_CMD 0xD0   // Read command opcode
#define MRDS1322_WRITE_CMD 0x00  // Write command opcode (actual observed)
#define MRDS1322_STOP_BYTE 0xFF  // Frame end delimiter
#define MRDS1322_STUFF_BYTE 0xFD // Byte-stuffing escape character

// Command Processing Timeouts
#define PC_COMMAND_TIMEOUT_MS                                                  \
  2000 // Maximum time to wait for PC command response
#define READ_RESPONSE_TIMEOUT_MS                                               \
  1500 // Maximum time to wait for MRDS1322 read response

/*
 * MRDS1322 Protocol Example:
 *
 * Read PS Command:  FE D0 C8 08 FF
 *   FE = Start byte
 *   D0 = Read command
 *   C8 = PS start address (0xC8)
 *   08 = Length (8 bytes)
 *   FF = Stop byte
 *
 * Response:         FE <8 PS bytes> FF
 *   FE = Start byte
 *   <data> = PS characters (with byte-stuffing if needed)
 *   FF = Stop byte
 *
 * Byte-Stuffing Rules:
 *   Data byte FD → FD 00
 *   Data byte FE → FD 01
 *   Data byte FF → FD 02
 */

/* =====================================================================================
 *                          ESP32 HARDWARE PIN CONFIGURATION
 * =====================================================================================
 */

// ===== SERIAL COMMUNICATION PINS =====
#define SERIAL1_RX 21 // MRDS1322 RX pin (GPIO21)
#define SERIAL1_TX 22 // MRDS1322 TX pin (GPIO22)
// Note: Serial (USB) uses default pins and is initialized separately

// ===== TFT DISPLAY PINS (NV3007 - SPI Interface) =====
#define TFT_CS 16   // Chip Select (GPIO16)
#define TFT_RST 5   // Reset (GPIO5)
#define TFT_DC 17   // Data/Command (GPIO17)
#define TFT_MOSI 18 // SPI MOSI Data (GPIO18)
#define TFT_SCLK 19 // SPI Clock (GPIO19)
#define TFT_BL 4    // Backlight Control (GPIO4)

// ===== VU METER ADC INPUT PINS =====
#define PIN_L A3 // Left audio channel: GPIO39 (ADC1_CH3)
#define PIN_R A0 // Right audio channel: GPIO36 (ADC1_CH0)

/*
 * Complete Pin Assignment Reference:
 *
 * ┌──────────────┬─────────────────────┬──────────────────────────┐
 * │ ESP32 GPIO   │ Function            │ Connected To             │
 * ├──────────────┼─────────────────────┼──────────────────────────┤
 * │ GPIO21       │ SERIAL1_RX          │ MRDS1322 TX              │
 * │ GPIO22       │ SERIAL1_TX          │ MRDS1322 RX              │
 * │ GPIO16       │ TFT_CS              │ NV3007 Chip Select       │
 * │ GPIO5        │ TFT_RST             │ NV3007 Reset             │
 * │ GPIO17       │ TFT_DC              │ NV3007 Data/Command      │
 * │ GPIO18       │ TFT_MOSI            │ NV3007 SPI Data          │
 * │ GPIO19       │ TFT_SCLK            │ NV3007 SPI Clock         │
 * │ GPIO4        │ TFT_BL              │ NV3007 Backlight         │
 * │ GPIO39 (A3)  │ PIN_L (ADC1_CH3)    │ Left Audio Input         │
 * │ GPIO36 (A0)  │ PIN_R (ADC1_CH0)    │ Right Audio Input        │
 * │ USB (N/A)    │ Serial (PC Comm)    │ PC USB Connection        │
 * └──────────────┴─────────────────────┴──────────────────────────┘
 */
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

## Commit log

2025-10-09 Initial commit - RDS Stereo HW Encoder Controller
2025-10-09 Add hardware project folder
    [Stereo RDS Encoder-Analog Board.brd, Stereo RDS Encoder-Analog Board.sch, Stereo RDS Encoder-Digital Board.brd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]
2025-10-10 Add hardware design files documentation to README
    Updated the Hardware Requirements section to mention that the hardware/ folder contains complete PCB design files (schematics and PCB layout) that have been built and fully tested.
2025-10-10 Add MRDS1322 documentation and hardware resources
    - Added MRDS1322 RDS Encoder section to README with Pira.cz attribution
    - Included MRDS1322 datasheet in HARDWARE folder
    - Added NJM2035 datasheet for reference
    - Included TinyRDS Setup installer for Windows

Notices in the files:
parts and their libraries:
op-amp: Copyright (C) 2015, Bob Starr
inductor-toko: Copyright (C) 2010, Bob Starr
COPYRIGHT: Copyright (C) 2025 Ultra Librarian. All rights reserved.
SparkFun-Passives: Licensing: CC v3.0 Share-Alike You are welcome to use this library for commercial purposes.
